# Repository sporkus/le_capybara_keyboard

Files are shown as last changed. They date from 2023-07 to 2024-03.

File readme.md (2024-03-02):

Le Capybara Keyboard
----

Capacitive sensing (aka Topre) keyboard in Le Chiffre layout

## Status
Fully tested 

## Manufacturing
Plates have m2 threaded holes for securing the plate and switches to the PCB.  DIY tapping is not difficult if your plate manufacturer does not offer tapping services.

Recommended plate material is 1.2mm steel. Plate files are in the expected physical dimensions. No kerf adjustments have been applied. The dxf files have been used successfully with SendCutSend and LaserBoost. JLCPCB is not recommnded for the plates without further testing to adapt to their milling process.

- [PCB production files](./production/)
- [Plate files](./plate/)

## Assembly

EC housing from DESKEYS and KLC playground have been tested.

#### Parts needed
- 32 - 34: 1u EC housing + slider
- 0 - 2: 2u EC housing + slider
- 34 - 36: Rubber domes
- 34 - 36: Conical springs
- 16: m2 x 8mm screws

**Optional**
- Silencing rings
- EC 11 rotary encoder or 1 MX switch for the center button

## Misc
#### 3D assembly preview
* [online viewer](https://3dviewer.net/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)
* [step assembly](./documentation/le_capybara-3D.step)

#### PCB Renders
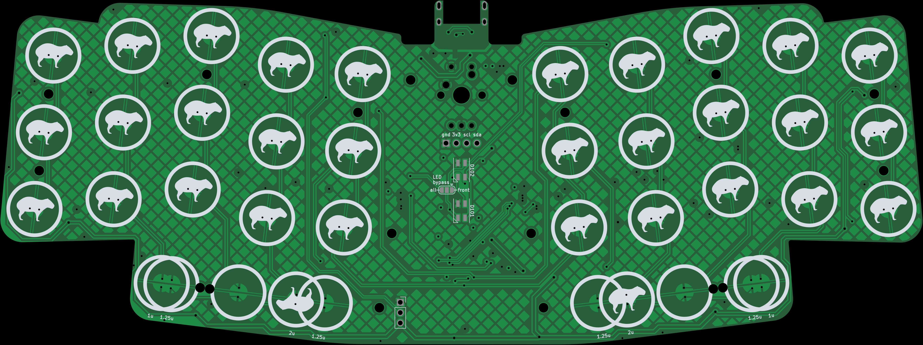
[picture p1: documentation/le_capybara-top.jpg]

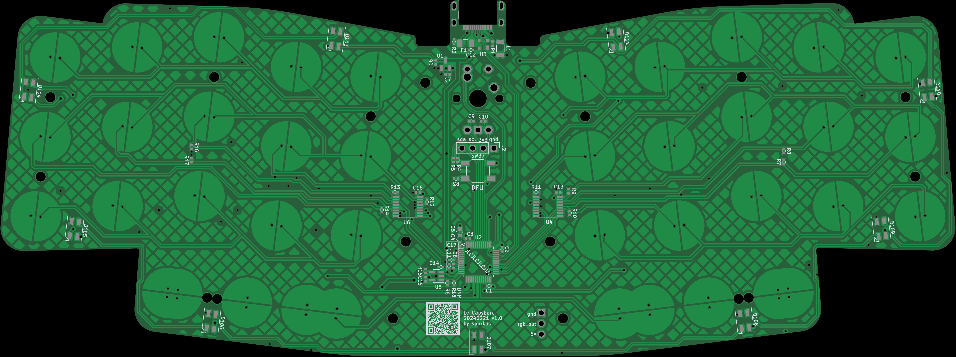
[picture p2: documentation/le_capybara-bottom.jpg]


#### Interactive BoM
Download and open this [html](./documentation/le_capybara-ibom.html) locally

#### Schematic
[pdf](./documentation/le_capybara-schematic.pdf)

## Change log
- 2024-02-21: V1.0 release for group buy. Change mounting method to tapped plate for ease of assembly.

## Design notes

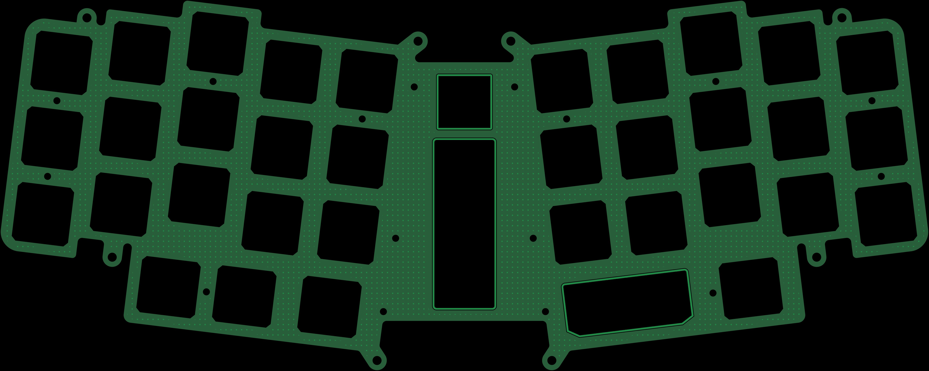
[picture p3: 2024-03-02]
plate/asymmetric/plate_asym-top.jpg

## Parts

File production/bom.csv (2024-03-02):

Designator | Footprint | Quantity | Value | LCSC Part #
C1, C10, C12, C17, C2, C3, C4, C9 | 0402 | 8 | 100nF | C307331
C11 | 0402 | 1 | 1u
C13, C15, C16, C8 | 0402 | 4 | 100n | C307331
C14 | 0402 | 1 | 220pF | C1530
C5 | 0603 | 1 | 10uF
C6, C7 | 0402 | 2 | 1uF | C52923
D101, D102, D103, D104, D105, D106, D107, D108, D109, D110, D111 | LED_SK6812MINI_PLCC4_3.5x3.5mm_P1.75mm | 11 | SK6812MINI
F1 | 1206 | 1 | ASMD1206-150 | C135341
H1, H10, H11, H12, H13, H14, H15, H16, H17, H18, H2, H3, H4, H5, H6, H7, H8, H9 | MountingHole_2.2mm_M2 | 18 | M2 Hole
J1 | USB4510031A | 1 | USB_C sink board 1.3mm | C3019717
J101 | PinSocket_1x03_P2.54mm_Vertical | 1 | Conn_01x03_Female
JP2 | SolderJumper-3_P1.3mm_Open_RoundedPad1.0x1.5mm | 1 | SolderJumper_3_Open
L1 | 1206 | 1 | 60R@100MHz | C33600
R1, R2 | 0402 | 2 | 5.1k
R10, R11, R12, R13, R14, R16, R17, R6, R7, R8, R9 | 0402 | 11 | 100k | C25741
R15 | 0402 | 1 | 1k | C11702
R3 | 0402 | 1 | 10k
R4, R5 | 0402 | 2 | 4.7k
SW32, SW33 | capy_pad_2U_90deg | 2 | EC_SW
SW35 | MX-Solderable-1U | 1 | SW_Push
SW37 | SW_SPST_SKQG_WithoutStem | 1 | SKQGABE010 | C115351
SW39, SW40, SW42, SW43 | ec_pad_1U_90deg | 4 | EC_SW
U1 | SOT-23 | 1 | XC6206PxxxMR-Regulator_Linear | C5446
U2 | LQFP-48_7x7mm_P0.5mm | 1 | STM32F072CBT6
U3 | SOT-143 | 1 | PRTR5V0U2X | C2827688
U4, U6 | TSSOP-16_4.4x5mm_P0.65mm | 2 | 74HC4051 | C5645
U5 | SOT-23-5 | 1 | OPA354AIDBVR

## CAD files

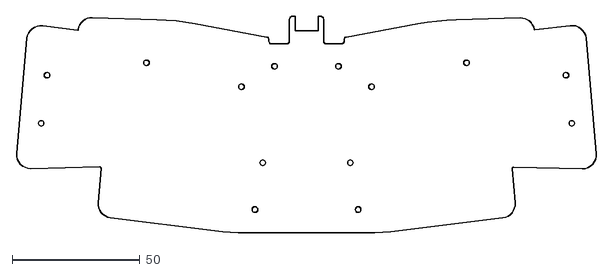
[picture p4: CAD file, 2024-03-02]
documentation/le_capybara-Edge_Cuts.dxf
227.6 x 85.0

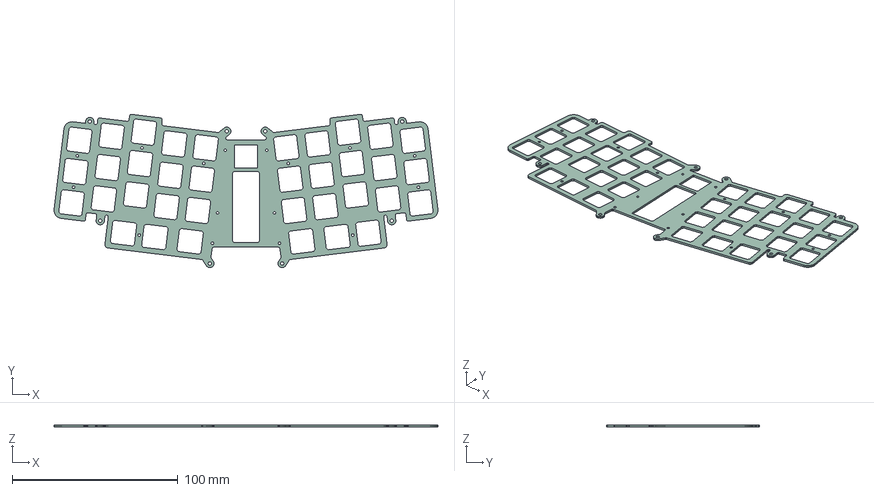
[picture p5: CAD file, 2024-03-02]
plate/36-keys/plate_36keys-3D.step
231.6 x 92.5 x 1.20 mm

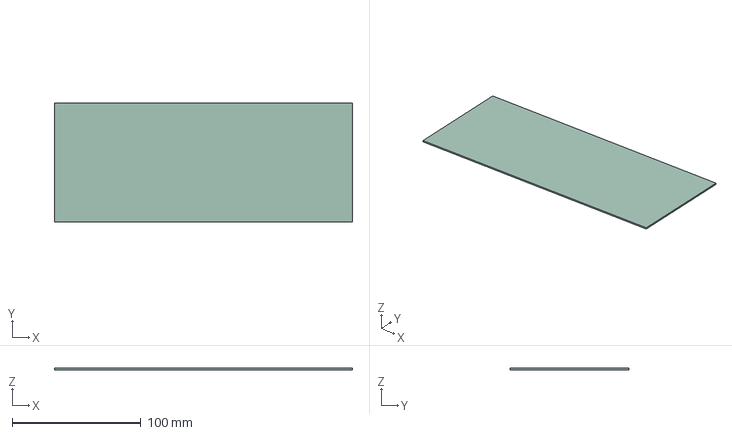
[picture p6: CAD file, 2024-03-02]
plate/asymmetric/plate_asym-3D.step
231.8 x 92.7 x 1.20 mm

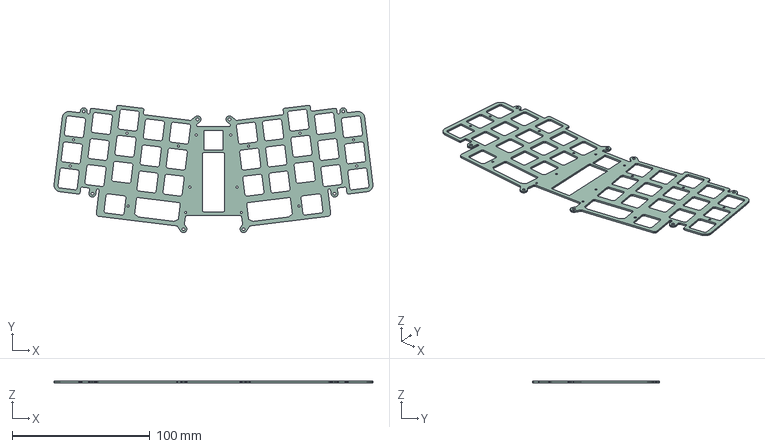
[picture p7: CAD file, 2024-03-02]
plate/classic/plate-3D.step
231.6 x 92.5 x 1.20 mm

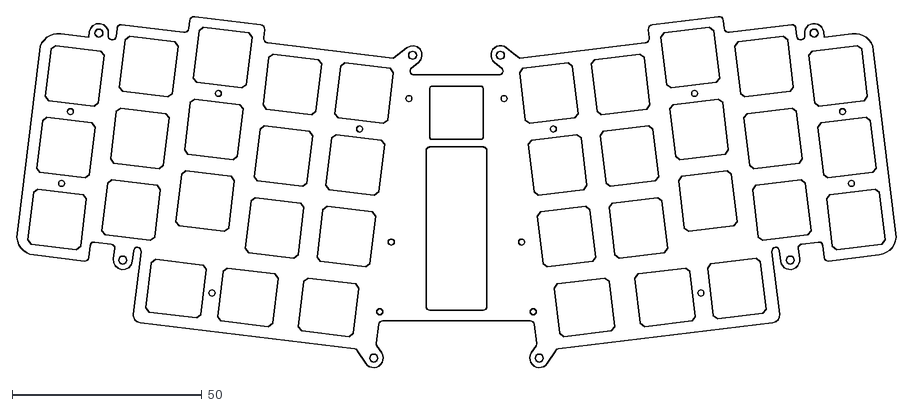
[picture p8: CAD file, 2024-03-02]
plate/36-keys/plate_36keys-Edge_Cuts.dxf
231.9 x 92.6

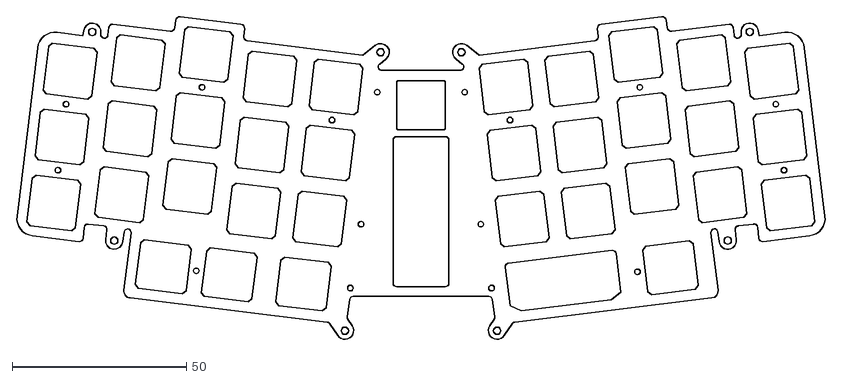
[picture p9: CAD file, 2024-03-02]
plate/asymmetric/plate_asym-Edge_Cuts.dxf
231.9 x 92.6

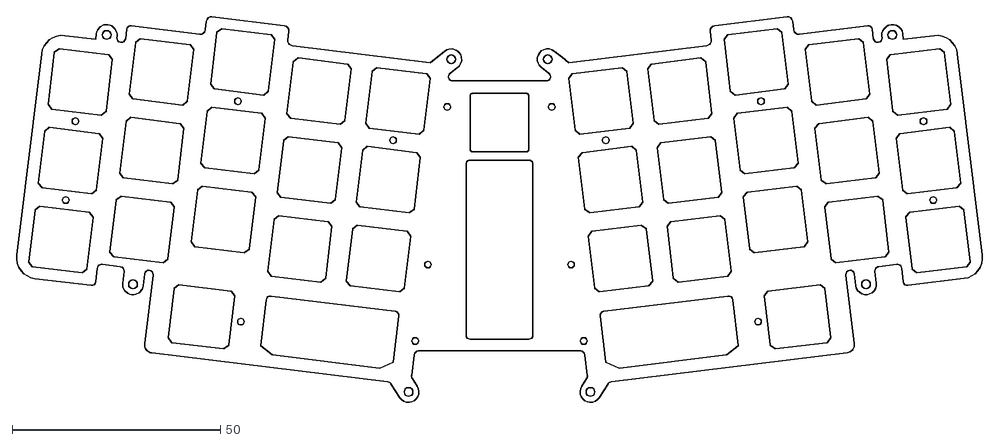
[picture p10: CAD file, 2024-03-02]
plate/classic/plate-Edge_Cuts.dxf
231.9 x 92.6

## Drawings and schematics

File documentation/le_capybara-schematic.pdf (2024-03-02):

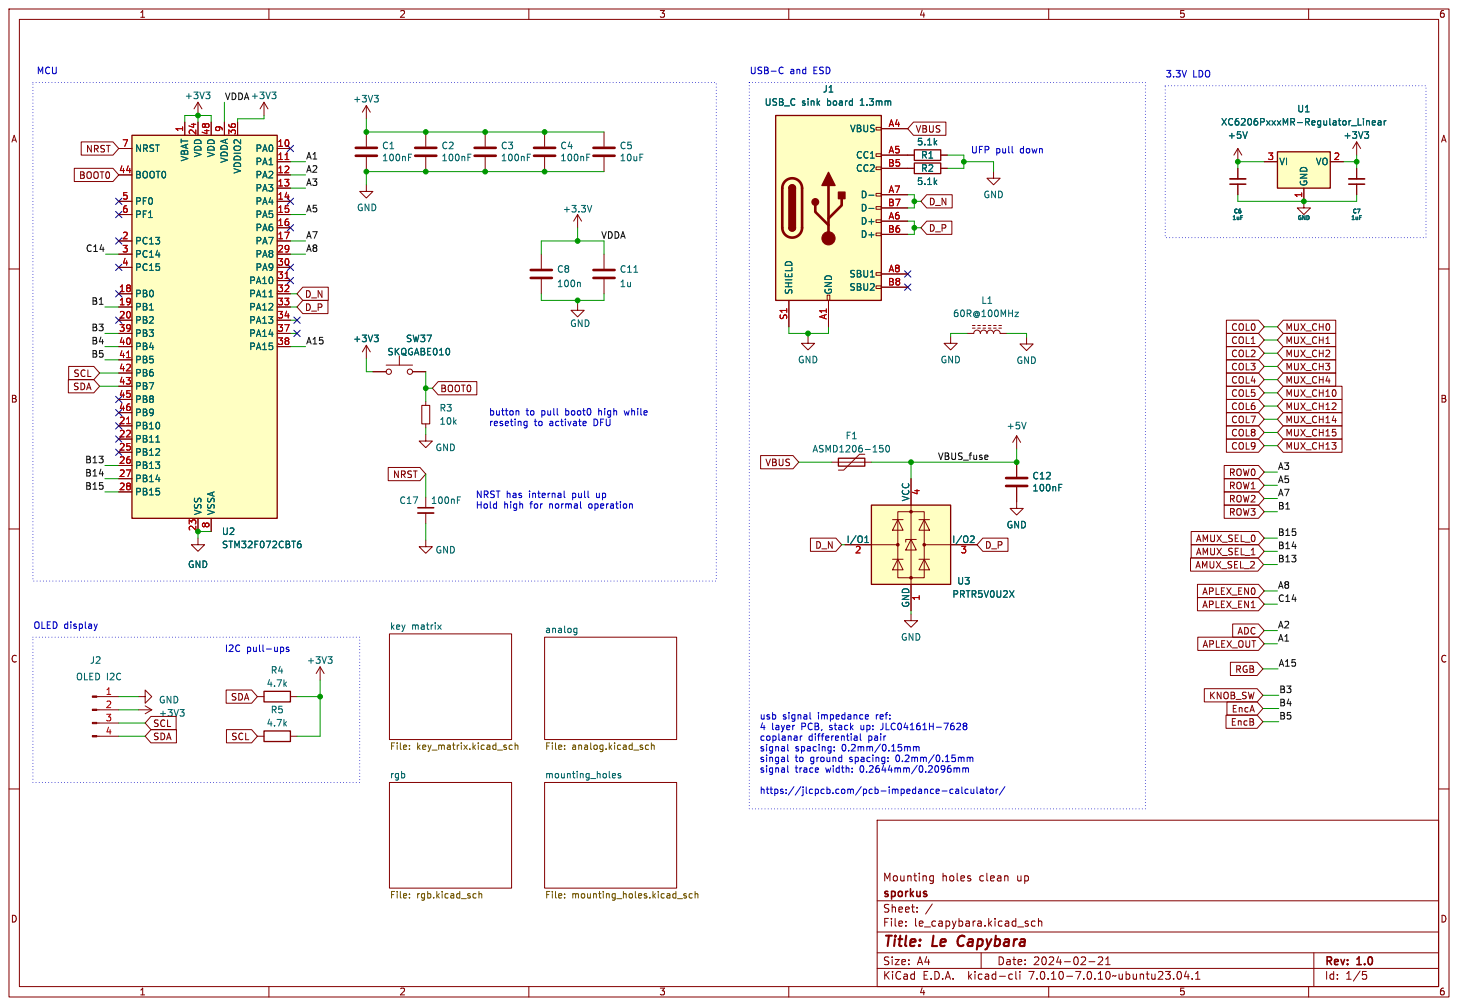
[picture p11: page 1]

1 PA0 10 PA1 11 PA2 12 PA3 13 PA4 14 PA5 15 PA6 16 PA7 17 PB0 18 PB1 19 PC13 2 PB2 20 PB10 21 PB11 22 VSS 23 VDD 24 PB12 25 PB13 26 PB14 27 PB15 28 PA8 29 PC14 3 PA9 30 PA10 31 PA11 32 PA12 33 PA13 34 VDDIO2 36 PA14 37 PA15 38 PB3 39 PC15 4 PB4 40 PB5 41 PB6 42 PB7 43 BOOT0 44 PB8 45 PB9 46 VDD 48 PF0 5 PF1 6 NRST 7 VSSA

button to pull boot0 high while

Mounting holes clean up
File: le_capybara.kicad_sch Sheet: / sporkus

Id: 1/5 Title: Le Capybara

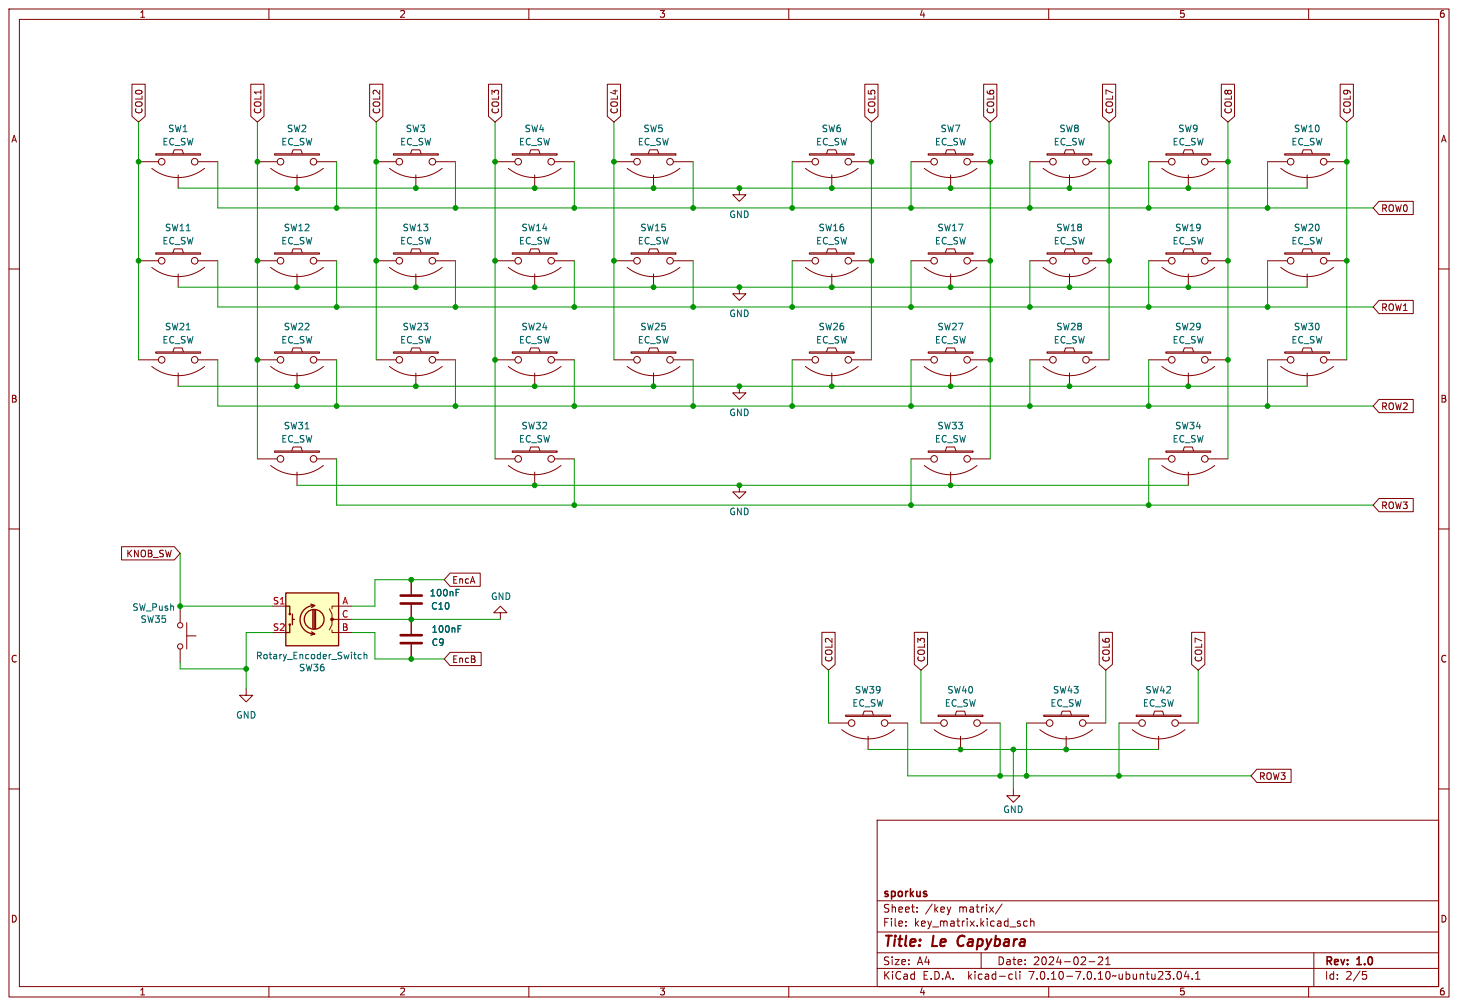
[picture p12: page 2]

File: key_matrix.kicad_sch Sheet: /key matrix/ sporkus C9

Id: 2/5 Title: Le Capybara

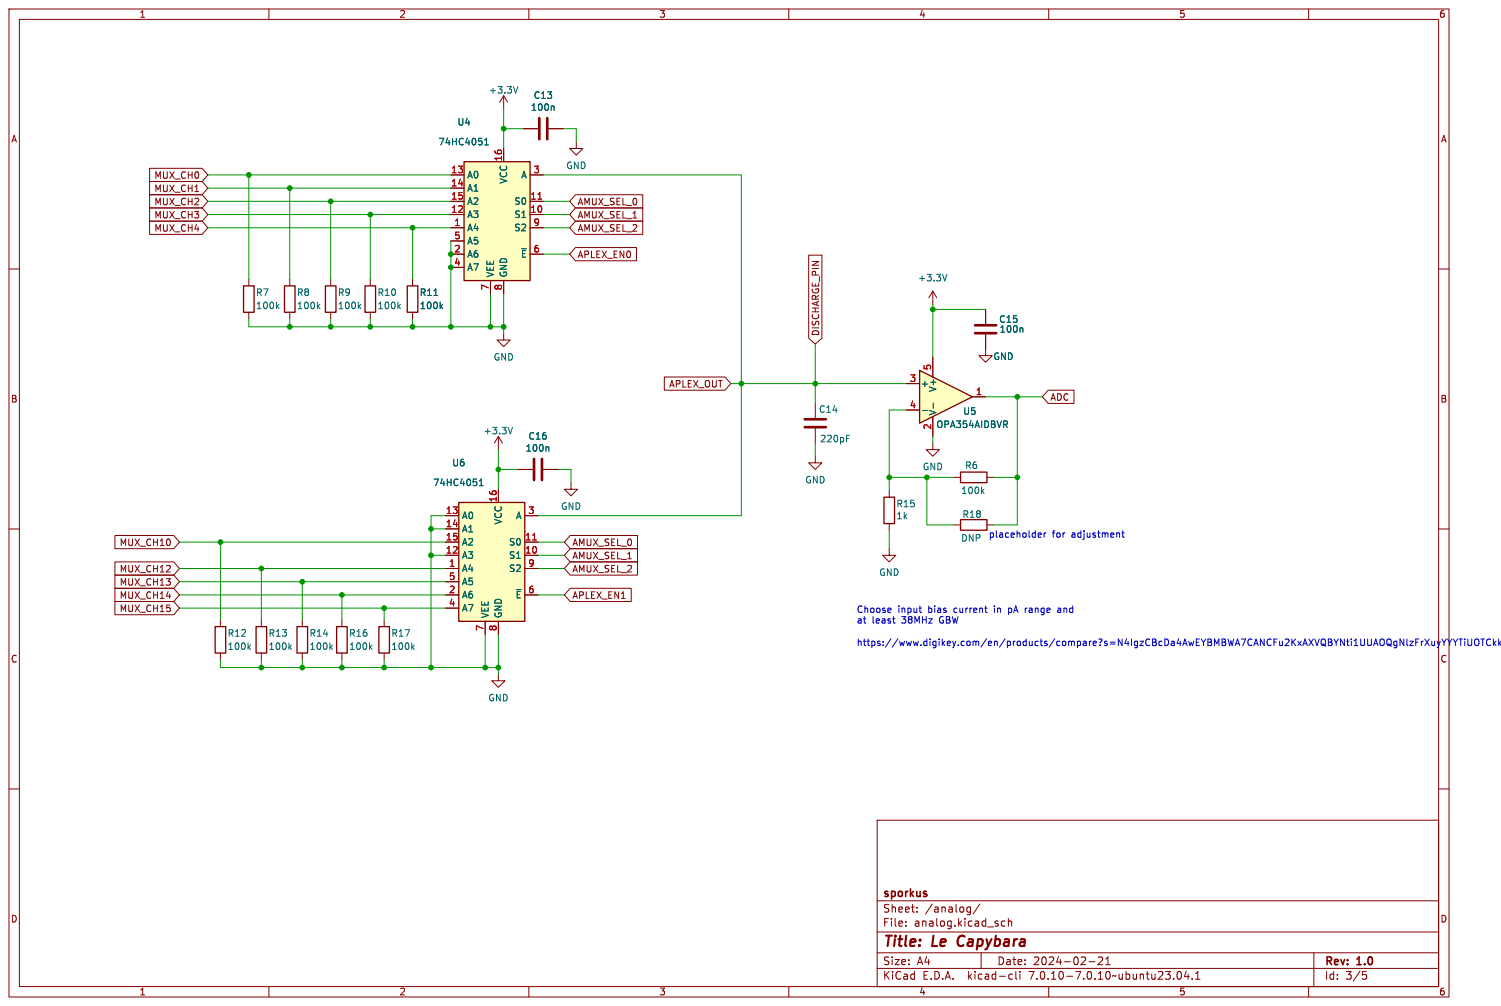
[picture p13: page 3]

https://www.digikey.com/en/products/compare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

File: analog.kicad_sch Sheet: /analog/
Id: 3/5 Title: Le Capybara

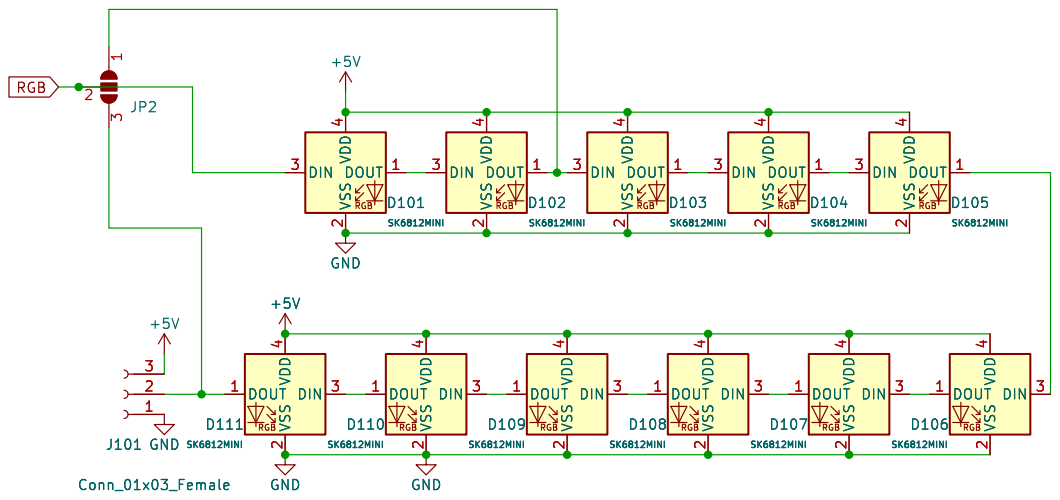
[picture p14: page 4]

sporkus
File: rgb.kicad_sch Sheet: /rgb/
Id: 4/5 Title: Le Capybara

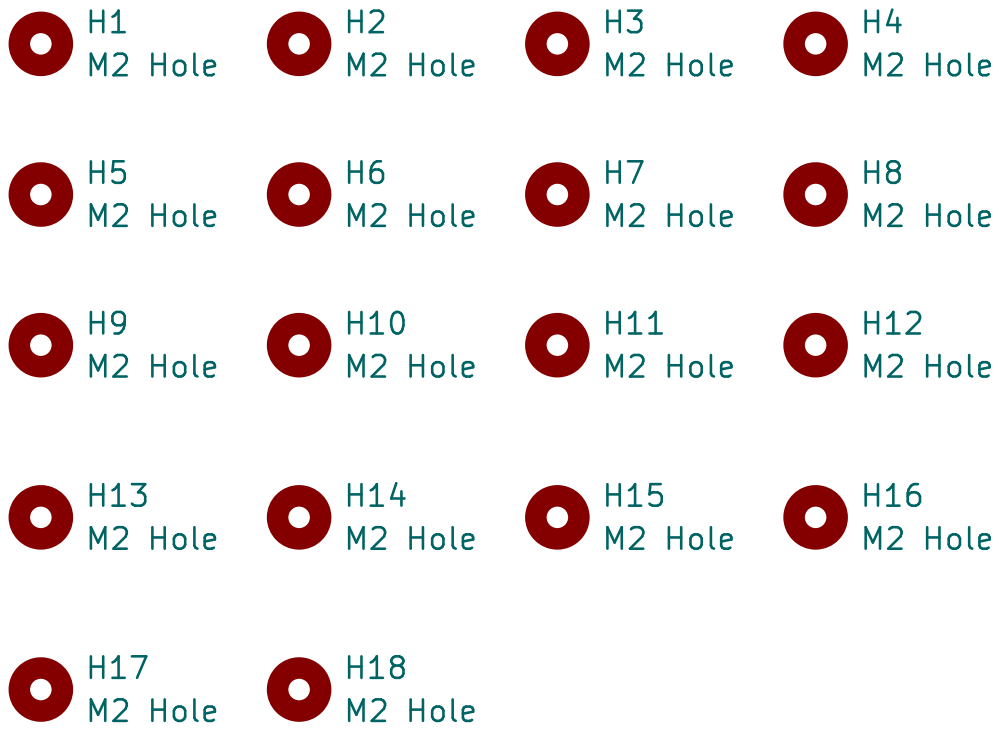
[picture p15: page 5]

sporkus
File: mounting_holes.kicad_sch Sheet: /mounting_holes/
Id: 5/5 Title: Le Capybara

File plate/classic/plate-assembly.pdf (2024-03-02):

# Le Capybara Plate

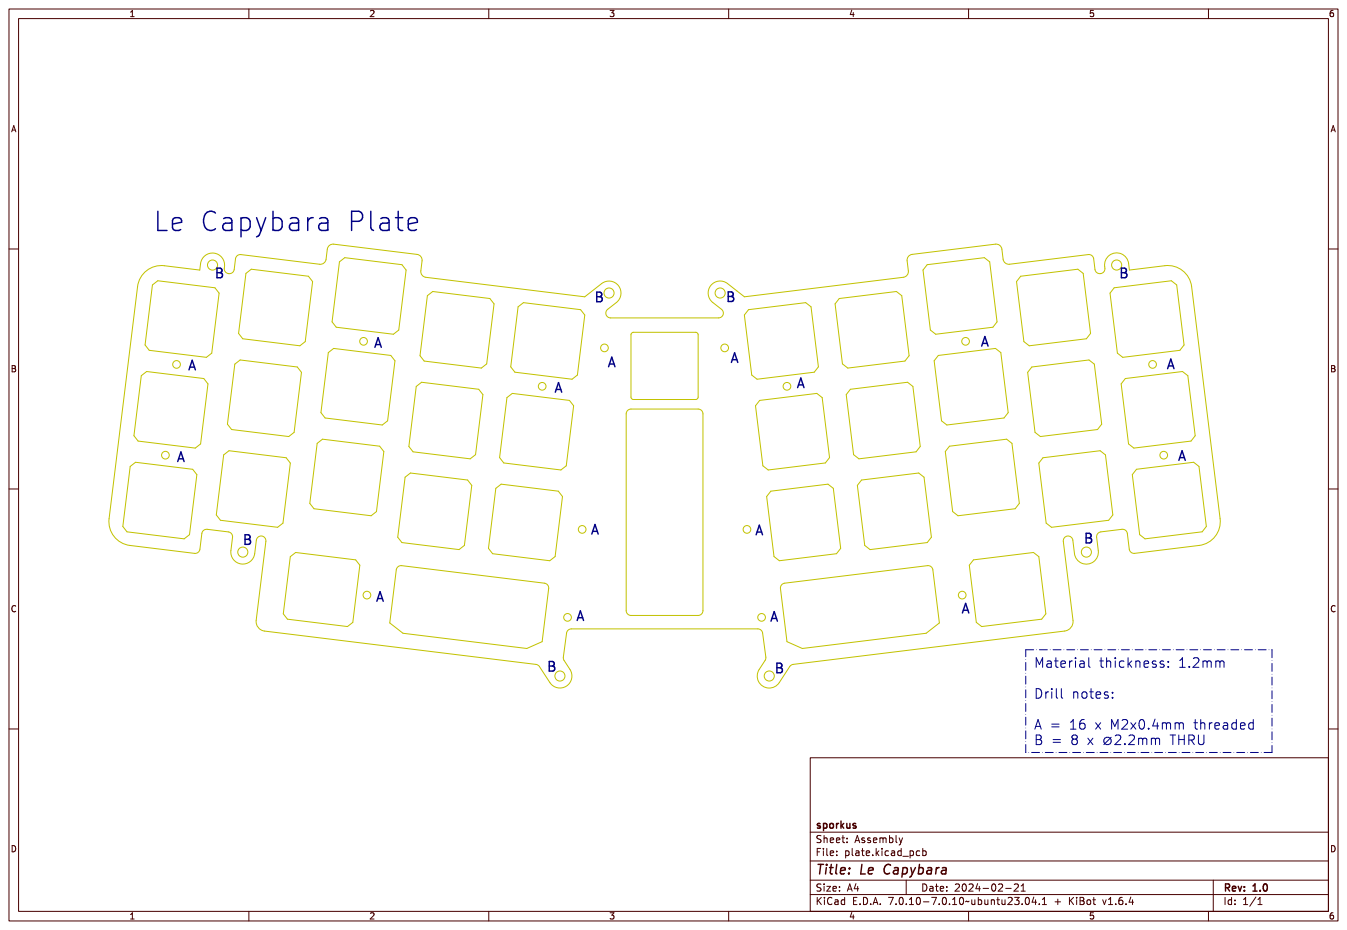
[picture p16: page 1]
Date: 2024-02-21; KiCad; E.D.A. 7.0.10-7.0.10~ubuntu23.04.1; + KiBot v1.6.4; Size: A4; Rev: 1.0; File:; plate.kicad_pcb; B = 8 x ⌀2.2mm THRU; A = 16 x M2x0.4mm threaded; Drill notes:; Material; thickness:

sporkus
Sheet: Assembly
Title: Le Capybara

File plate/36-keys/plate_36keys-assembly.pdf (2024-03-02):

# Le Capybara Plate (36 keys)

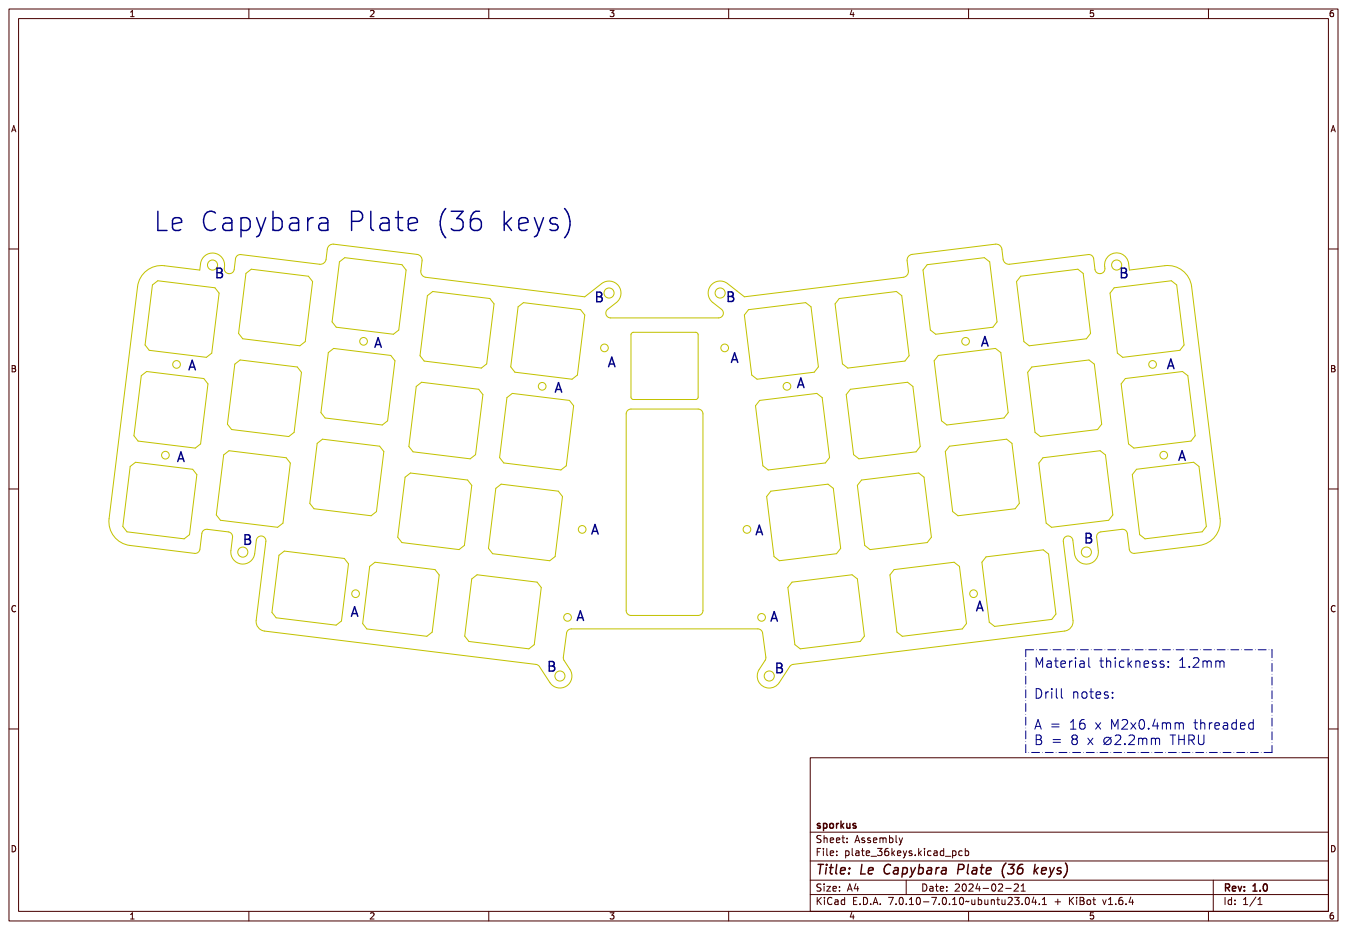
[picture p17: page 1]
Date: 2024-02-21; KiCad; E.D.A. 7.0.10-7.0.10~ubuntu23.04.1; + KiBot v1.6.4; Size: A4; Rev: 1.0; File:; plate_36keys.kicad_pcb; B = 8 x ⌀2.2mm THRU; A = 16 x M2x0.4mm threaded; Drill notes:; Material; thickness:

sporkus
Sheet: Assembly
Title: Le Capybara Plate (36 keys)

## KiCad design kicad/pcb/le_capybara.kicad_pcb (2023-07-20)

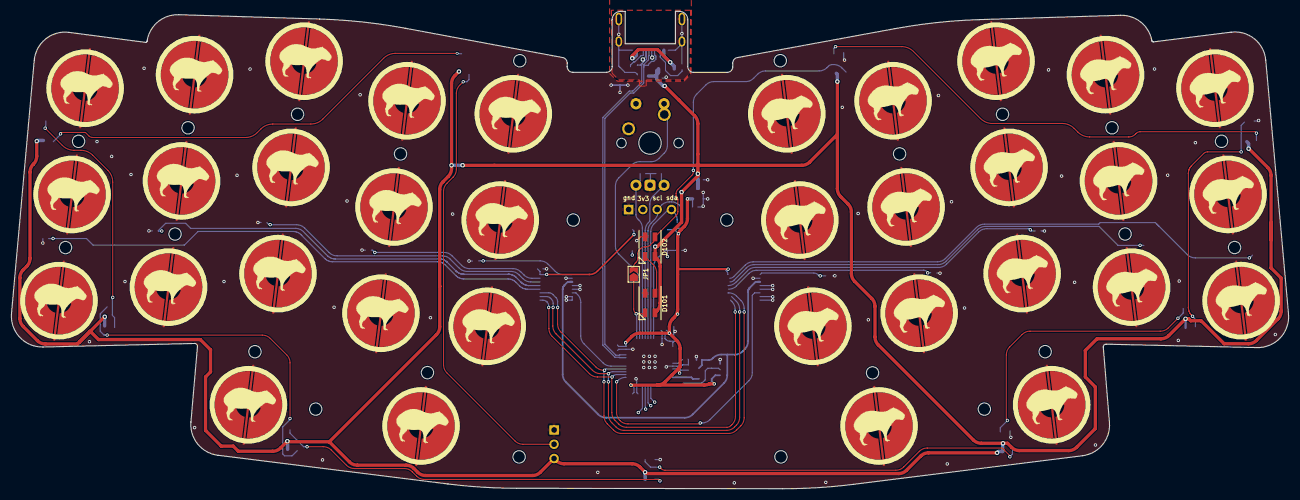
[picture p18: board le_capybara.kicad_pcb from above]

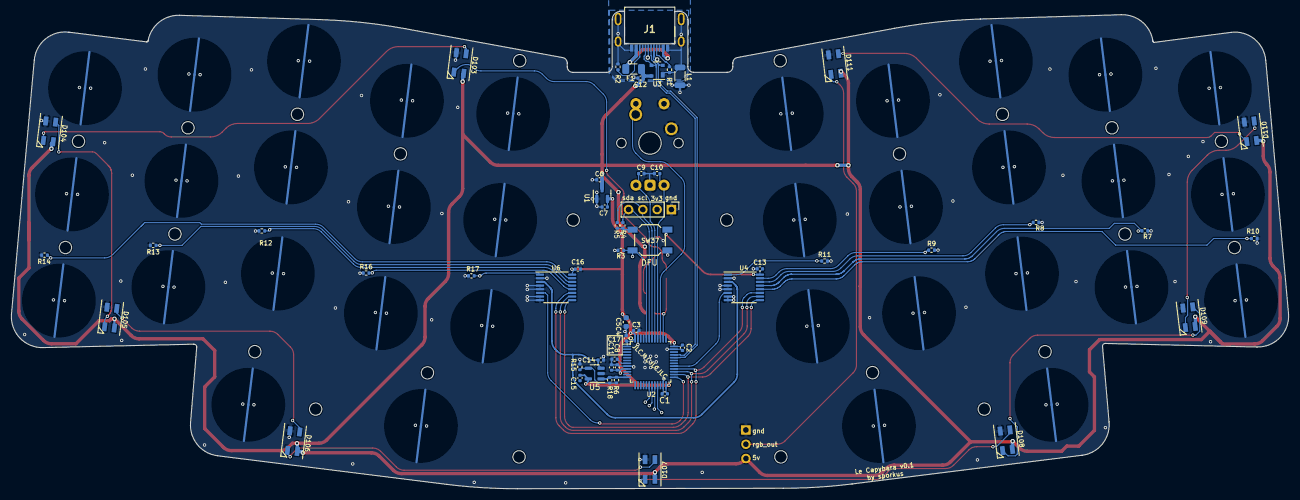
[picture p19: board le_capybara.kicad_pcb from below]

Board: 4 copper layers, 227.3 x 85.0 mm, 119 parts (55 on the bottom side), 49 nets.

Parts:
C1, C2, C3, C4, C9, C10, C12, C17: 100nF; C_0402_1005Metric
C5: 10uF; C_0603_1608Metric
C6, C7: 1uF; C_0402_1005Metric
C8, C13, C15, C16: 100n; C_0402_1005Metric
C11: 1u; C_0402_1005Metric
C14: 220pF NP0; C_0402_1005Metric
D101, D102, D103, D104, D105, D106, D107, D108, D109, D110, D111: SK6812MINI; LED_SK6812MINI_PLCC4_3.5x3.5mm_P1.75mm
F1: ASMD1206-150; Fuse_1206_3216Metric
H1, H2, H3, H4, H5, H6, H7, H8, H9, H10, H11, H12, H13, H14, H15, H16, H17, H18, H19, H20, H21, H22, H23, H24: MountingHole; MountingHole_2.2mm_M2_DIN965
J1: USB_C sink board 1.6mm; USB4510031A
J2: OLED I2C; PinHeader_1x04_P2.54mm_Vertical
J101: Conn_01x03_Female; PinSocket_1x03_P2.54mm_Vertical
JP1: Jumper_2_Open; SolderJumper-2_P1.3mm_Open_TrianglePad1.0x1.5mm
L1: 60R@100MHz; L_1206_3216Metric
R1, R2: 5.1k; R_0402_1005Metric
R3: 10k; R_0402_1005Metric
R4, R5: 4.7k; R_0402_1005Metric
R6, R7, R8, R9, R10, R11, R12, R13, R14, R16, R17: 100k; R_0402_1005Metric
R15: 1k; R_0402_1005Metric
R18: DNP; R_0402_1005Metric
SW1, SW2, SW3, SW4, SW5, SW6, SW7, SW8, SW9, SW10, SW11, SW12, SW13, SW14, SW15, SW16, SW17, SW18, SW19, SW20, SW21, SW22, SW23, SW24, SW25, SW26, SW27, SW28, SW29, SW30, SW31, SW32, SW33, SW34: EC_SW; capy_pad_1U_90deg
SW35: SW_Push; MX-Solderable-1U
SW36: Rotary_Encoder_Switch; ROT_Alps_EC11E-Switch
SW37: SKQGABE010; SW_SPST_SKQG_WithoutStem
U1: XC6206PxxxMR-Regulator_Linear; SOT-23
U2: STM32F072CBT6; LQFP-48_7x7mm_P0.5mm
U3: PRTR5V0U2X; SOT-143
U4, U6: 74HC4051; TSSOP-16_4.4x5mm_P0.65mm
U5: OPA354AIDBVR; SOT-23-5

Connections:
+3V3: C1.1, C2.1, C3.1, C4.1, C5.1, C7.2, C8.1, C11.1, C13.2, C15.2, C16.2, J2.2, R4.2, R5.2, SW37.1, U1.2 (VO), U2.1 (VBAT), U2.9 (VDDA), U2.24 (VDD), U2.36 (VDDIO2), U2.48 (VDD), U4.16 (VCC), U5.5 (V+), U6.16 (VCC)
+5V: C6.2, C12.1, D101.4 (VDD), D102.4 (VDD), D103.4 (VDD), D104.4 (VDD), D105.4 (VDD), D106.4 (VDD), D107.4 (VDD), D108.4 (VDD), D109.4 (VDD), D110.4 (VDD), D111.4 (VDD), F1.2, J101.3 (Pin_1), U1.3 (VI), U3.4 (VCC)
ADC: R6.1, R18.1, U2.12 (PA2), U5.1
AMUX_SEL_0: U2.28 (PB15), U4.11 (S0), U6.11 (S0)
AMUX_SEL_1: U2.27 (PB14), U4.10 (S1), U6.10 (S1)
AMUX_SEL_2: U2.26 (PB13), U4.9 (S2), U6.9 (S2)
APLEX_EN0: U2.29 (PA8), U4.6 (~E)
APLEX_EN1: U2.25 (PB12), U6.6 (~E)
APLEX_OUT: C14.1, U4.3 (A), U5.3 (+), U6.3 (A)
BOOT0: R3.1, SW37.2, U2.44 (BOOT0)
COL0: R10.1, SW1.2, SW11.2, SW21.2, U4.12 (A3)
COL1: R7.1, SW2.2, SW12.2, SW22.2, U4.13 (A0)
COL2: R8.1, SW3.2, SW13.2, SW23.2, SW31.2, U4.14 (A1)
COL3: R9.1, SW4.2, SW14.2, SW24.2, SW32.2, U4.15 (A2)
COL4: R11.1, SW5.2, SW15.2, SW25.2, U4.1 (A4)
COL5: R17.1, SW6.1, SW16.1, SW26.1, U6.1 (A4)
COL6: R16.1, SW7.1, SW17.1, SW27.1, SW33.1, U6.12 (A3)
COL7: R12.1, SW8.1, SW18.1, SW28.1, SW34.1, U6.13 (A0)
COL8: R13.1, SW9.1, SW19.1, SW29.1, U6.14 (A1)
COL9: R14.1, SW10.1, SW20.1, SW30.1, U6.15 (A2)
D_N: J1.A7 (D-), J1.B7 (D-), U2.32 (PA11), U3.2 (I/O1)
D_P: J1.A6 (D+), J1.B6 (D+), U2.33 (PA12), U3.3 (I/O2)
EncA: C10.1, SW36.A, U2.40 (PB4)
EncB: C9.1, SW36.B, U2.41 (PB5)
GND: C1.2, C2.2, C3.2, C4.2, C5.2, C6.1, C7.1, C8.2, C9.2, C10.2, C11.2, C12.2, C13.1, C14.2, C15.1, C16.1, C17.2, D101.2 (VSS), D102.2 (VSS), D103.2 (VSS), D104.2 (VSS), D105.2 (VSS), D106.2 (VSS), D107.2 (VSS), D108.2 (VSS), D109.2 (VSS), D110.2 (VSS), D111.2 (VSS), J1.A1 (GND), J1.A12 (GND), J1.S1 (SHIELD), J2.1, J101.1 (Pin_3), L1.1, L1.2, R1.1, R2.1, R3.2, R7.2, R8.2, R9.2, R10.2, R11.2, R12.2, R13.2, R14.2, R15.2, R16.2, R17.2, SW1.3 (SG), SW2.3 (SG), SW3.3 (SG), SW4.3 (SG), SW5.3 (SG), SW6.3 (SG), SW7.3 (SG), SW8.3 (SG), SW9.3 (SG), SW10.3 (SG), SW11.3 (SG), SW12.3 (SG), SW13.3 (SG), SW14.3 (SG), SW15.3 (SG), SW16.3 (SG), SW17.3 (SG), SW18.3 (SG), SW19.3 (SG), SW20.3 (SG), SW21.3 (SG), SW22.3 (SG), SW23.3 (SG), SW24.3 (SG), SW25.3 (SG), SW26.3 (SG), SW27.3 (SG), SW28.3 (SG), SW29.3 (SG), SW30.3 (SG), SW31.3 (SG), SW32.3 (SG), SW33.3 (SG), SW34.3 (SG), SW35.1, SW36.C, SW36.S2, U1.1 (GND), U2.8 (VSSA), U2.23 (VSS), U2.35 (VSS), U2.47 (VSS), U3.1 (GND), U4.2 (A6), U4.4 (A7), U4.5 (A5), U4.7 (VEE), U4.8 (GND), U5.2 (V-), U6.2 (A6), U6.4 (A7), U6.5 (A5), U6.7 (VEE), U6.8 (GND)
KNOB_SW: SW35.2, SW36.S1, U2.39 (PB3)
NRST: C17.1, U2.7 (NRST)
unnamed: D101.1 (DOUT), D102.3 (DIN)
unnamed: D102.1 (DOUT), D103.3 (DIN), JP1.2 (B)
unnamed: D103.1 (DOUT), D104.3 (DIN)
unnamed: D104.1 (DOUT), D105.3 (DIN)
unnamed: D105.1 (DOUT), D106.1 (DOUT)
unnamed: D106.3 (DIN), D107.1 (DOUT)
unnamed: D107.3 (DIN), D108.1 (DOUT)
unnamed: D108.3 (DIN), D109.1 (DOUT)
unnamed: D109.3 (DIN), D110.1 (DOUT)
unnamed: D110.3 (DIN), D111.1 (DOUT)
unnamed: D111.3 (DIN), J101.2
unnamed: J1.A5 (CC1), R1.2
unnamed: J1.B5 (CC2), R2.2
unnamed: R6.2, R15.1, R18.2, U5.4 (-)
RGB: D101.3 (DIN), JP1.1 (A), U2.38 (PA15)
ROW0: SW1.1, SW2.1, SW3.1, SW4.1, SW5.1, SW6.2, SW7.2, SW8.2, SW9.2, SW10.2, U2.18 (PB0)
ROW1: SW11.1, SW12.1, SW13.1, SW14.1, SW15.1, SW16.2, SW17.2, SW18.2, SW19.2, SW20.2, U2.19 (PB1)
ROW2: SW21.1, SW22.1, SW23.1, SW24.1, SW25.1, SW26.2, SW27.2, SW28.2, SW29.2, SW30.2, U2.20 (PB2)
ROW3: SW31.1, SW32.1, SW33.2, SW34.2, U2.21 (PB10)
SCL: J2.3, R5.1, U2.42 (PB6)
SDA: J2.4, R4.1, U2.43 (PB7)
VBUS: F1.1, J1.A4 (VBUS), J1.A9 (VBUS)

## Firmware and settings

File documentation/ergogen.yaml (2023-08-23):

meta:
  engine: 4.0.0
  name: le_capybara
  version: 0.1
  author: sporkus
  url: https://github.com/sporkus/

presets:
  mx_spaced:
    capx: 18.1
    capy: capx
    kx: 19.05
    ky: kx
    edge_cut_padding: 1
    split_angle: 7
    thumb_2nd_unit: 1.25
    thumb_main_unit: 2
    3thumbs_main_unit: 1.25

    # distance from inner top key to knob/center switch
    centerx: 24.347
    centery: 5.202

    originx: 120
    originy: -100

units:
  $extends: presets.mx_spaced
  edgex: capx/2 + edge_cut_padding  #distance from middle of the switch to pcb edge
  edgey: capy/2 + edge_cut_padding


points:
  # Keys/Switches
  # =============
  zones.matrix:
    mirror: &mirror
      ref: matrix_inner_top
      shift: [0, 0]
      distance: 24.347 * 2
    anchor.shift: [originx, originy]
    rotate: -split_angle
    key:
      width: capx
      height: capy
      spread: kx
      padding: ky
      bind: [edgex, edgey]
    rows:
      bottom:
      home:
      top:
    columns:
      pinky:
      ring.key:
        stagger: 1/4ky
      middle.key:
        stagger: 0.25ky
      index.key:
        stagger: -0.25ky
      inner:

  zones.3thumbs:
    mirror: *mirror
    key:
      $extends: points.zones.matrix.key
      width: 1 * capx
    anchor:
      - ref: matrix_ring_bottom
        shift: [kx * (1 - 0.25), -ky]
    columns:
      3rd:
      2nd:
      main:
        key:
          width: 1.25 * capx
          shift: [kx * 0.25/2, 0]
  
  zones.2thumbs:
    mirror: *mirror
    key:
      $extends: points.zones.matrix.key
      width: 1 * capx
    anchor:
      - ref: matrix_ring_bottom
        shift: [kx * (1 - 0.25/2) , -ky]
    columns:
      2nd:
        key.width: 1.25 * capx
      main:
        key.width: 2 * capx
        key.shift: [kx * 1.25 / 2, 0]

  zones.knob:
    key:
      $extends: points.zones.matrix.key
      width: 1 * capx
    anchor:
      - ref: matrix_inner_top
        orient: split_angle
        shift: [centerx, -centery]

outlines:
  _switch_cutout:
    - what: rectangle
      where:
        - /matrix_.*/
        - /.thumb.*/
        - /knob/
      size: [10, 10]
      bound: false
  _switch_pos:
    - what: circle
      where:
        - /matrix_.*/
        - /.*thumb.*/
        - /knob/
      radius: 1
      bound: false
  _switch_comment:
    - what: rectangle
      operation: stack
      where:
        - /matrix_.*/
        - /.thumb.*/
        - /knob/
      size: [kx, ky]
      bound: false
  _keycaps:
    - what: rectangle
      where:
        - /matrix_.*/
        - /.*thumb.*/
      size: [capx, capy]
      bound: false
  _edge_cut:
    - what: rectangle
      where:
        - /matrix_/
      bound: true
    - what: rectangle
      where: /thumb/
      size: [1, 1]
      bound: true

  edge_cut:
    - name: _edge_cut
      fillet: 3.5
  preview:
    - edge_cut
    - ^_switch_pos
    - ^_switch_cutout
    - ^_switch_comment

  
  kicad_ref:
    - ^_switch_pos
    - ^_switch_comment

  kicad_center:
    - ^_switch_pos


pcbs.le_capybara:
  outlines.main:
    outline: kicad_ref
    layer: Eco2.User
  footprints:
    - what: mx
      where:
        - /matrix_.*/
        - /.thumb.*/
        - knob
      params:
        from: GND
        to: "{{name}}"
        reverse: true
        keycaps: true

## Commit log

2023-07-20 try kibot
    [LeChiffre_Plate.kicad_pcb, LeChiffre_Plate.sch, Plate 5.14.32 PM.dxf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]
2023-08-09 rerouted pcb
    [analog.kicad_sch, key_matrix.kicad_sch, le_capybara.kicad_sch]
2023-08-23 getting ready for prototype
    [analog.kicad_sch, bom.csv, designators.csv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]
2023-09-02 Major fixes after prototype order
    Fixed the following:
    - wrong RGB schematic, D106-D111 doesn't work
    - discharge pin from analog circuit was not connected
    - plate holes had the wrong diameter
    [analog.kicad_sch, key_matrix.kicad_sch, le_capybara.kicad_sch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]
2023-09-11 schematic fix and plate tolerance fix
    [bom.csv, designators.csv, key_matrix.kicad_sch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]
2023-09-11 change plate thickness
    [le_capybara_plate.kicad_pcb]
2023-10-20 versioning pcb
2023-12-08 remove top mounting hole for chiffre+ compatibility
    [kicad_center.dxf, le_capybara-Edge_Cuts.dxf, le_capybara_plate.kicad_pcb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]
2024-02-03 adding three-thumbed plate
    [key_matrix.kicad_sch, plate_3_thumbs.kicad_pcb, plate_3_thumbs.kicad_sch]
2024-02-06 add asymmetric plate
    [key_matrix.kicad_sch, le_capybara_plate_3thumb_3dp.step, le_capybara_plate_3thumb_3dp.stl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]
2024-02-06 fix 3-thumb plate kibot issue
    [key_matrix.kicad_sch, le_capybara_plate-3D.step, le_capybara_plate-Edge_Cuts.dxf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]
2024-02-06 Making production plates
    - Change EC mounting hole size from 2.2mm clearance to 1.6mm for M2
    tapping
    - Reduce hole count for cost reduction
    - Add drilling/fabrication notes
    [plate_asym.kicad_pcb, plate_asym.kicad_sch]
2024-02-06 reorganizing plate folder
    [le_capybara_plate-3D.step, le_capybara_plate-Edge_Cuts.dxf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]
2024-02-06 fix kibot pcb_print
2024-02-06 Production plates - all versions
    [key_matrix.kicad_sch, le_capybara_plate-3D.step, le_capybara_plate-Edge_Cuts.dxf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]
2024-02-07 fix 1.6mm hole footprint
    [plate-3D.step, plate-Edge_Cuts.dxf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]
2024-02-21 Clean up after prototyping
    - Doc update
    - remove uncessary files
    - remove two more mounting holes in the "chiffre gap" area
    [key_matrix.kicad_sch, plate.kicad_pcb, plate.kicad_sch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]
2024-02-21 remove notes
    [plate_asym.kicad_pcb]
2024-02-22 Remove extra mounting holes from PCB and update version number.
    [analog.kicad_sch, key_matrix.kicad_sch, le_capybara.kicad_sch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]
2024-02-22 updated gerbers and doc
    [bom.csv, designators.csv]
2024-03-02 remove extra notation
    [plate.kicad_pcb]
